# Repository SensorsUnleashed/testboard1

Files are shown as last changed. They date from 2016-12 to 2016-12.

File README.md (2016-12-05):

# relayboard
Simple board that will be powered by both mains and a button cell battery.
It is able to:
* Operate a Single Pole Double Throw relay
* Connection for a [Optical Utility Meter LED Pulse Sensor](https://openenergymonitor.org/emon/opticalpulsesensor) from OpenEnergyMonitor
* Has a i2c eeprom
* Can attach to a Sensors Unleashed radio module
* If mains is lost, the relay will release, but the radio will still be operating. This means that messages can still be send even though power is removed.

This board has many uses, but some ideas could be:
Use any installation in the house as input for the system. This device will detect if a button has been toggled, and send messages as instructed. Perhaps turning on/off lamps or plugs in another location in a house.

The board has been ordered from DirtyPCBs 2016-12-05. When tested I will make sure to update this document.

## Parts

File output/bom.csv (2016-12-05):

Reference | "Quantity" | "Value" | "Footprint" | "Datasheet" | "Characteristics" | "Package ID" | "Supplier" | "Manufacturer Name" | "Manufacturer Part Number" | "Description" | "Supplier Order number" | "Notes"
BT1 | 1 | CR2032 | SensorsUnleashed:BATT_CR2032_MPD | http://www.memoryprotectiondevices.com/datasheets/BC2032-F1-datasheet.pdf | Coin, 20.0mm | smd, Holder (Open) | Digi Key | MPD (Memory Protection Devices) | BC2032-F1 | Coin Cell, Holder | BC2032-F1-CT-ND
C1 | 1 | 100nF | Capacitors_SMD:C_0805 |  | 25V | 0805
C2 | 1 | 22uF | Capacitors_SMD:C_0805 | http://datasheets.avx.com/F98.pdf | Tantalum, ESR 4Ohm, 10V, 20% | 0805 | digikey, 478-8649-2-ND | AVX Corporation | F981A226MSA
C3 | 1 | 1nF | Capacitors_SMD:C_0805 |  | 50V, X7R | 0805
D1 | 1 | BAS321 | Diodes_SMD:SOD-323 | http://www.nxp.com/documents/data_sheet/BAS321.pdf | Vr=200V, Io=250mA, Vf=1.25V@200mA | SOD-323 | Digi Key | NXP Semiconductors | BAS321,115 | Fast Recovery Rectifiers | 568-6002-1-ND
IC1 | 1 | AT24C256C-SSHL-T | Housings_SOIC:SOIC-8_3.9x4.9mm_Pitch1.27mm | http://www.atmel.com/images/atmel-8568-seeprom-at24c256c-datasheet.pdf | 256K (32K x 8) eeprom, i2c | 8-SOIC | Aliexpress |  |  |  | https://www.aliexpress.com/item/Free-shipping-10pcs-lot-AT24C256C-SSHL-T-EEPROM-serial-AT24C256C-screen-2ECL-original-authentic/32699367011.html
J1 | 1 | RJ45 | Connect:RJ45_8 |  |  |  |  | Optical Utility Meter LED Pulse Sensor |  |  |  | https://openenergymonitor.org/emon/opticalpulsesensor
K1 | 1 | RELAY_1RT | SensorsUnleashed:Relay_SRD_XVDC-SL-C_Series |  |  |  | Aliexpress
P1 | 1 | Supply | Connect:AK300-2
P2 | 1 | HLK-PM01 | SensorsUnleashed:HLK-PM01 | https://www.aliexpress.com/item/5pcs-TSP-05-replace-HLK-PM01-AC-DC-220V-to-5V-mini-power-supply-module-intelligent/32409558042.html | 100-240VAC in, 5VDC/3W out |  | Aliexpress |  |  |  |  | Meets CE and UL; written, but not proven!
P3 | 1 | Sensors Unleashed Radio | SensorsUnleashed:zb3219PA_radio
P4 | 1 | Relay | Connect:AK300-3
Q1 | 1 | FDN304P | SensorsUnleashed:SSOT-3 |  | 20V 2.4A | SSOT3 |  | Fairchild Semiconductor | FDN304P | MOSFET P-CH
Q2, Q3 | 2 | BC849 | TO_SOT_Packages_SMD:SOT-23 |  |  | SOT23
R1, R2, R3 | 3 | 330k | Resistors_SMD:R_0805 | https://industrial.panasonic.com/ww/products/resistors/chip-resistors/chip-resistors/anti-sulfurated-thick-film-chip-resistors/ERJS1DF3303U | 1%, | 0805
R10 | 1 | 0R | Resistors_SMD:R_0805 |  | 1% | 0805
R4, R5, R8 | 3 | 10k | Resistors_SMD:R_0805 |  | 1% | 0805
R6 | 1 | 100R | Resistors_SMD:R_0805 |  | 1% | 0805
R7 | 1 | 4.7k | Resistors_SMD:R_0805 |  | 1% | 0805
R9 | 1 | 100k | Resistors_SMD:R_0805 |  | 1% | 0805
U1 | 1 | AMS1117 | TO_SOT_Packages_SMD:SOT-223 |  | Fixed 3.3V, 1A | SOT-223 |  | Advanced Monolithic Systems | AMS1117-3.3

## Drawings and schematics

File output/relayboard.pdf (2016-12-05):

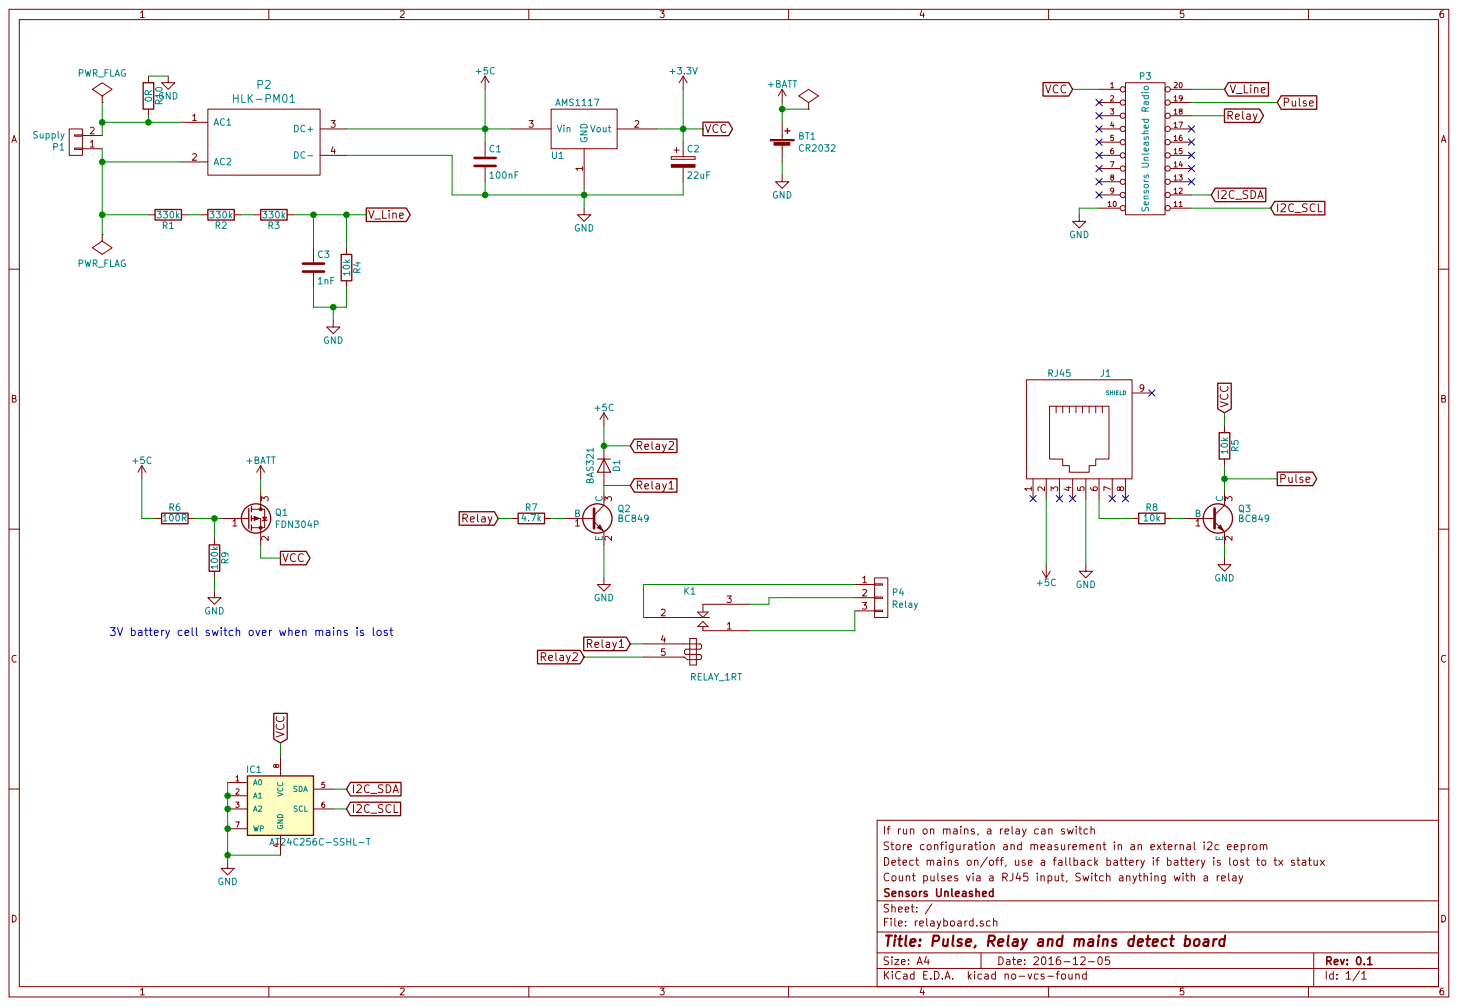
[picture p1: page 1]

3V battery cell switch over when mains is lost

4 SDA 5 SCL 6 WP 7 VCC

If run on mains, a relay can switch
Store configuration and measurement in an external i2c eeprom
Detect mains on/off, use a fallback battery if battery is lost to tx statux
File: relayboard.sch Sheet: / Sensors Unleashed Count pulses via a RJ45 input, Switch anything with a relay

Id: 1/1 Title: Pulse, Relay and mains detect board

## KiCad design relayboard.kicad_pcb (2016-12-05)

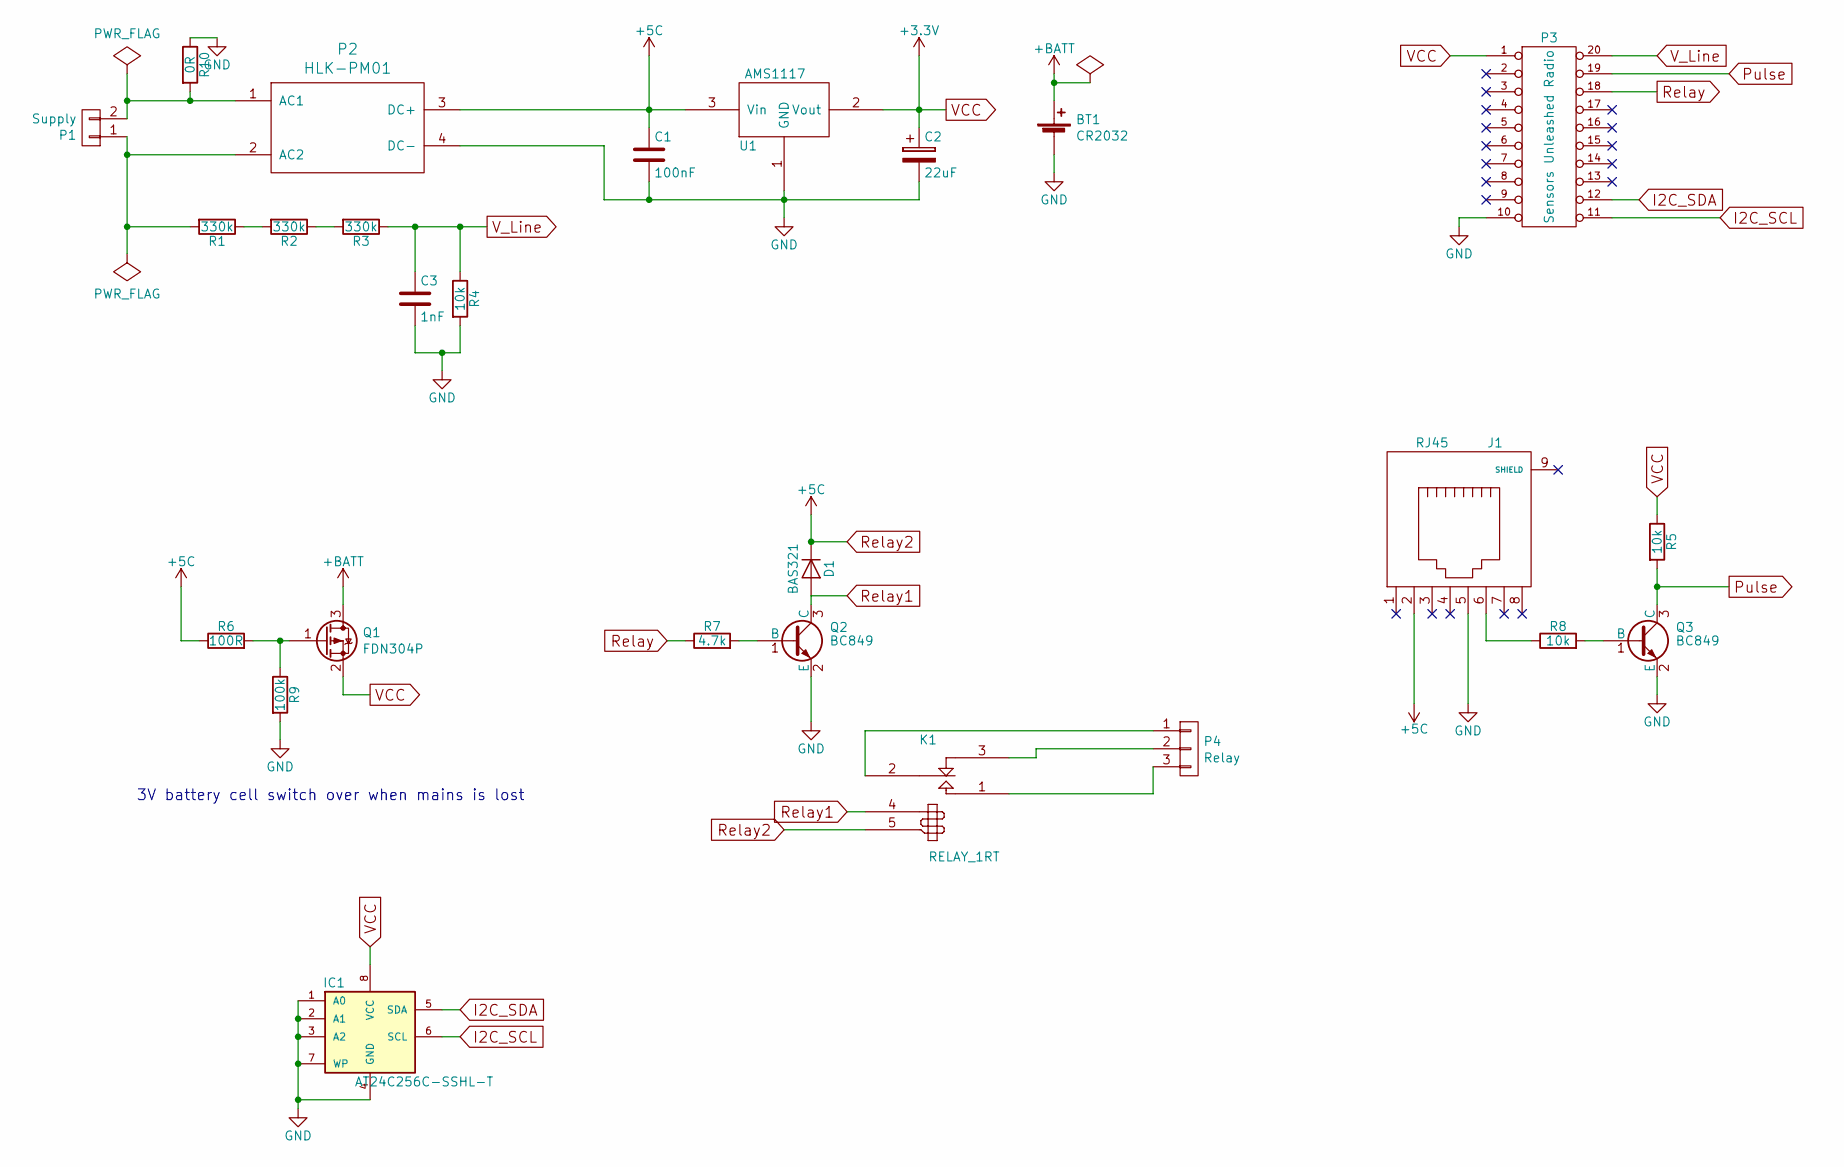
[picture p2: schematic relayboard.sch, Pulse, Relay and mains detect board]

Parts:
BT1: CR2032; BATT_CR2032_MPD; Manufacturer Part Number BC2032-F1
C1: 100nF; C_0805
C2: 22uF; C_0805; Manufacturer Part Number F981A226MSA
C3: 1nF; C_0805
D1: BAS321; SOD-323; Manufacturer Part Number BAS321,115
IC1: AT24C256C-SSHL-T; SOIC-8_3.9x4.9mm_Pitch1.27mm
J1: RJ45; RJ45_8
K1: RELAY_1RT; Relay_SRD_XVDC-SL-C_Series
P1: Supply; AK300-2
P2: HLK-PM01
P3: Sensors Unleashed Radio; zb3219PA_radio
P4: Relay; AK300-3
Q1: FDN304P; SSOT-3; Manufacturer Part Number FDN304P
Q2, Q3: BC849; SOT-23
R1, R2, R3: 330k; R_0805
R4, R5, R8: 10k; R_0805
R6: 100R; R_0805
R7: 4.7k; R_0805
R9: 100k; R_0805
R10: 0R; R_0805
U1: AMS1117; SOT-223; Manufacturer Part Number AMS1117-3.3

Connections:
+BATT: BT1.1 (+), Q1.3 (D)
GND: BT1.2 (-), C1.2, C2.2, C3.2, IC1.1 (A0), IC1.2 (A1), IC1.3 (A2), IC1.4 (GND), IC1.7 (WP), J1.5, P2.4 (DC-), P3.10, Q2.2 (E), Q3.2 (E), R4.2, R9.2, R10.1, U1.1 (GND)
I2C_SCL: IC1.6 (SCL), P3.11
I2C_SDA: IC1.5 (SDA), P3.12
unnamed: J1.6, R8.1
unnamed: K1.1 (T1), P4.3
unnamed: K1.2 (C1), P4.1
unnamed: K1.3 (R1), P4.2
unnamed: P1.1, P2.2 (AC2), R1.2
unnamed: P1.2, P2.1 (AC1), R10.2
unnamed: Q1.1 (G), R6.2, R9.1
unnamed: Q2.1 (B), R7.2
unnamed: Q3.1 (B), R8.2
unnamed: R1.1, R2.2
unnamed: R2.1, R3.2
Pulse: P3.19, Q3.3 (C), R5.2
Relay: P3.18, R7.1
Relay1: D1.2 (A), K1.4, Q2.3 (C)
Relay2: C1.1, D1.1 (K), J1.2, K1.5, P2.3 (DC+), R6.1, U1.3 (Vin)
VCC: C2.1, IC1.8 (VCC), P3.1, Q1.2 (S), R5.1, U1.2 (Vout)
V_Line: C3.1, P3.20, R3.1, R4.1

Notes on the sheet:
3V battery cell switch over when mains is lost

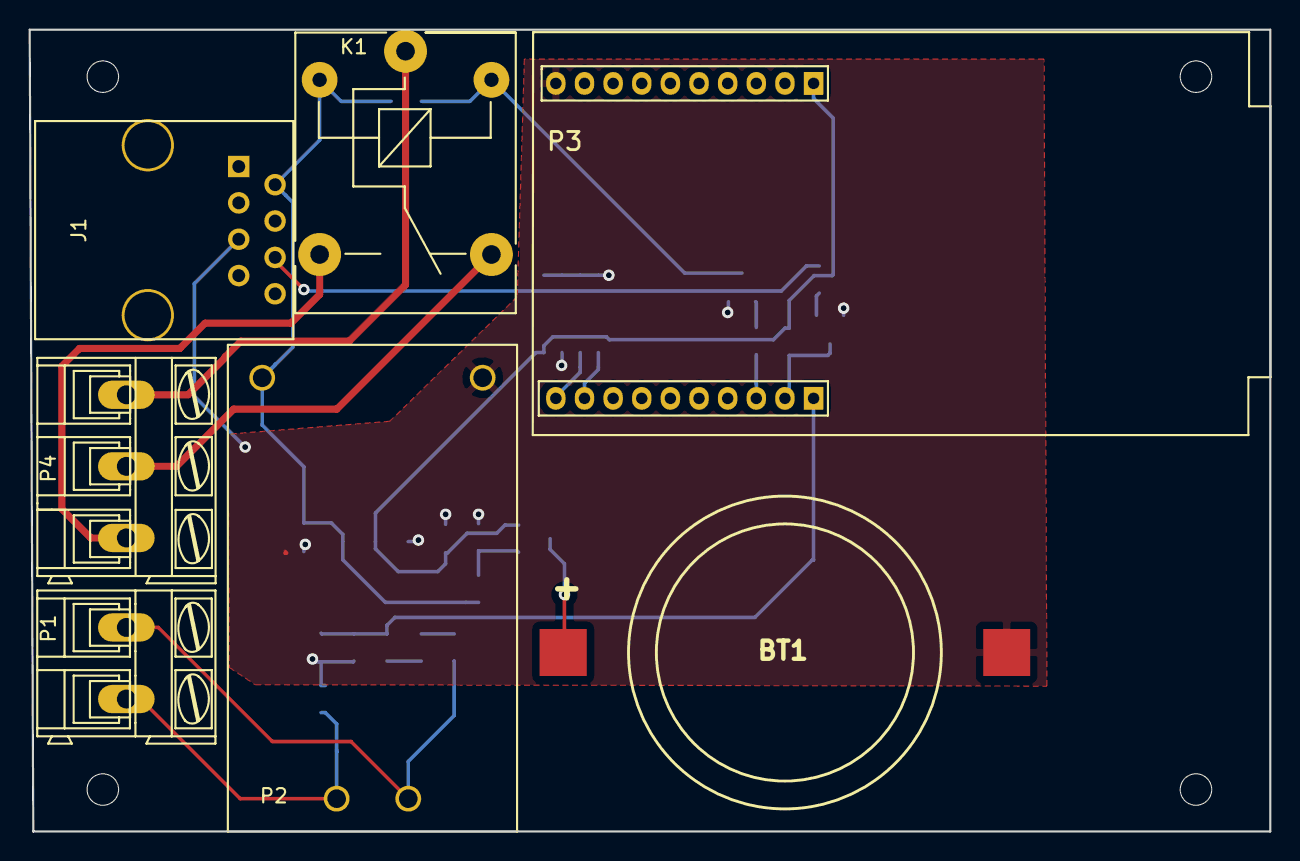
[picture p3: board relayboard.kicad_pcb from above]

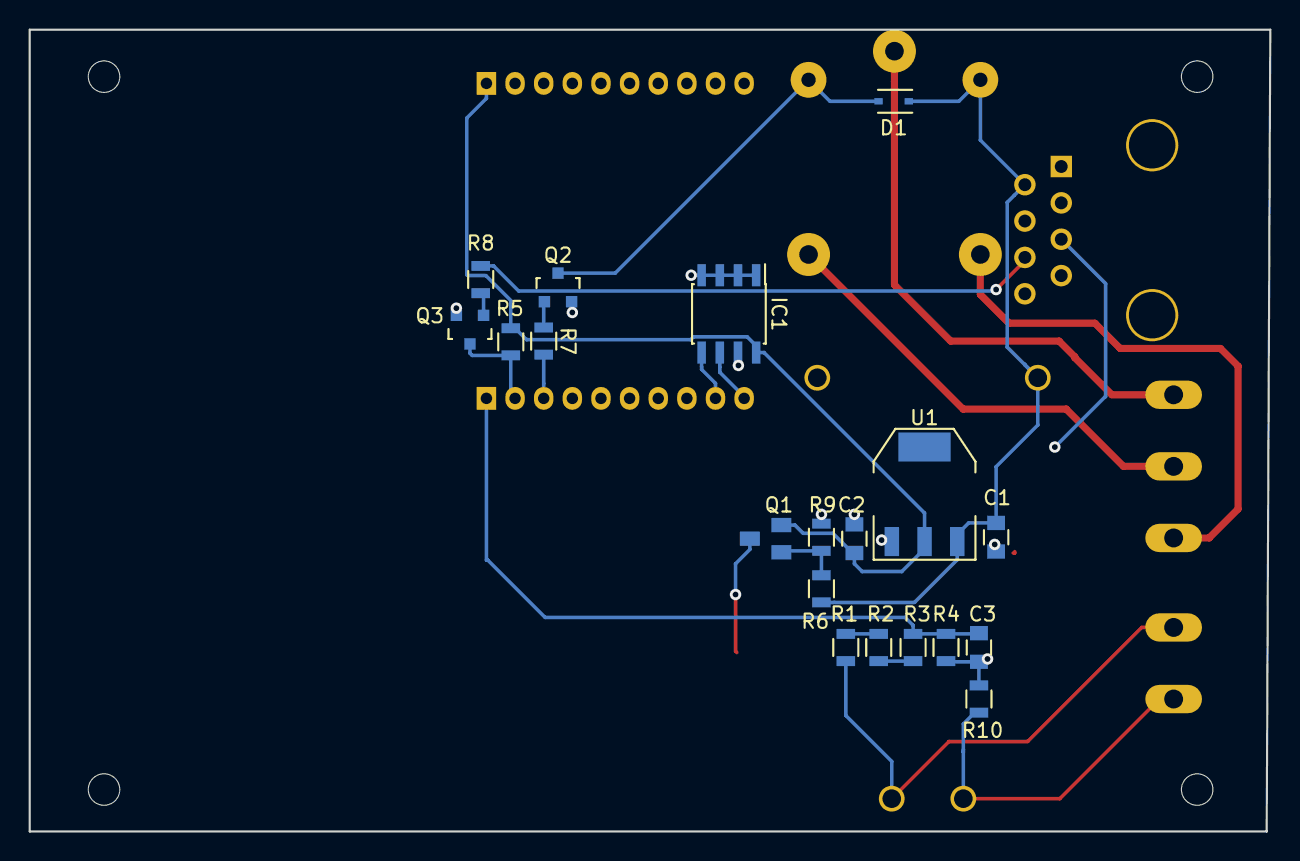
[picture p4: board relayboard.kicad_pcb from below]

Board: 2 copper layers, 86.7 x 56.0 mm, 26 parts (19 on the bottom side), 21 nets.

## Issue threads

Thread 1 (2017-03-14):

Power supply footprint +/- reversed

araldit, 2017-03-14:

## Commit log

2016-12-05 Layout finished. This will be sent to dirty pcb for manufactoring.
    [relayboard.kicad_pcb, relayboard.sch]
2016-12-05 Added gerber files
    [bom.csv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]
